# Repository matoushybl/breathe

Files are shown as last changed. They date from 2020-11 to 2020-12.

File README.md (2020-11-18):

# `app-template`

> Quickly set up a [`probe-run`] + [`defmt`] + [`flip-link`] embedded project

[`probe-run`]: https://crates.io/crates/probe-run
[`defmt`]: https://github.com/knurling-rs/defmt
[`flip-link`]: https://github.com/knurling-rs/flip-link

## Dependencies

#### 1. `flip-link`:

```console
$ cargo install flip-link
```

#### 2. `probe-run`:

``` console
$ cargo install probe-run
```

#### 3. [`cargo-generate`]:

```
$ cargo install cargo-generate
```

[`cargo-generate`]: https://crates.io/crates/cargo-generate

> *Note:* You can also just clone this repository instead of using `cargo-generate`, but this involves additional manual adjustments. [This flip-link CI patch](https://github.com/knurling-rs/flip-link/blob/main/.github/workflows/0001-configure-test-flip-link-app-for-nrf52840.patch) can serve as a reference on what to do.

## Setup

#### 1. Initialize the project template

``` console
$ cargo generate \
    --git https://github.com/knurling-rs/app-template \
    --branch main \
    --name my-app
```

If you look into your new `my-app` folder, you'll find that there are a few `TODO`s in the files marking the properties you need to set.

Let's walk through them together now.

#### 2. Set `probe-run` chip

Pick a chip from `probe-run --list-chips` and enter it into `.cargo/config.toml`.

If, for example, you have a nRF52840 Development Kit from one of [our workshops], replace `{{chip}}` with `nRF52840_xxAA`.

[our workshops]: https://github.com/ferrous-systems/embedded-trainings-2020

``` diff
 # .cargo/config.toml
 [target.'cfg(all(target_arch = "arm", target_os = "none"))']
-runner = "probe-run --chip {{chip}} --defmt"
+runner = "probe-run --chip nRF52840_xxAA --defmt"
```

#### 3. Adjust the compilation target

In `.cargo/config.toml`, pick the right compilation target for your board.

``` diff
 # .cargo/config.toml
 [build]
-target = "thumbv6m-none-eabi"    # Cortex-M0 and Cortex-M0+
-# target = "thumbv7m-none-eabi"    # Cortex-M3
-# target = "thumbv7em-none-eabi"   # Cortex-M4 and Cortex-M7 (no FPU)
-# target = "thumbv7em-none-eabihf" # Cortex-M4F and Cortex-M7F (with FPU)
+target = "thumbv7em-none-eabihf" # Cortex-M4F (with FPU)
```

#### 4. Add a HAL as a dependency

In `Cargo.toml`, list the Hardware Abstraction Layer (HAL) for your board as a dependency.

For the nRF52840 you'll want to use the [`nrf52840-hal`].

[`nrf52840-hal`]: https://crates.io/crates/nrf52840-hal

``` diff
 # Cargo.toml
 [dependencies]
-# some-hal = "1.2.3"
+nrf52840-hal = "0.11.0"
```

#### 5. Import your HAL

Now that you have selected a HAL, fix the HAL import in `src/lib.rs`

``` diff
 // my-app/src/lib.rs
-// use some_hal as _; // memory layout
+use nrf52840_hal as _; // memory layout
```

#### (6. Get a linker script)

Some HAL crates require that you manually copy over a file called `memory.x` from the HAL to the root of your project. For nrf52840-hal, this is done automatically so no action is needed. For other HAL crates, you can get it from your local Cargo folder, the default location is under:

```
~/.cargo/registry/src/
```

Not all HALs provide a memory.x file, you may need to write it yourself. Check the documentation for the HAL you are using.

#### 7. Run!

You are now all set to `cargo-run` your first `defmt`-powered application!
There are some examples in the `src/bin` directory.

Start by `cargo run`-ning `my-app/src/bin/hello.rs`:

``` console
$ # `rb` is an alias for `run --bin`
$ cargo rb hello
    Finished dev [optimized + debuginfo] target(s) in 0.03s
flashing program ..
DONE
resetting device
0.000000 INFO Hello, world!
(..)

$ echo $?
0
```

## Trying out the git version of defmt

This template is configured to use the latest crates.io release (the "stable" release) of the `defmt` framework.
To use the git version (the "development" version) of `defmt` follow these steps:

1. Install the *git* version of `probe-run`

``` console
$ cargo install --git https://github.com/knurling-rs/probe-run --branch main
```

2. Check which defmt version `probe-run` supports

``` console
$ probe-run --version
probe-run 0.1.4 (3521a42 2020-11-12)
supported defmt version: 3db6b41f08a5c866e6d6ed7103d01b0b0fe5a1f4
```

In the example output, the supported version is `3db6b41f08a5c866e6d6ed7103d01b0b0fe5a1f4`

3. Switch defmt dependencies to git: uncomment the last part of the root `Cargo.toml` and enter the hash reported by `probe-run --version`:

``` diff
-# [patch.crates-io]
-# defmt = { git = "https://github.com/knurling-rs/defmt", rev = "use defmt version reported by `probe-run --version`" }
-# defmt-rtt = { git = "https://github.com/knurling-rs/defmt", rev = "use defmt version reported by `probe-run --version`" }
-# defmt-test = { git = "https://github.com/knurling-rs/defmt", rev = "use defmt version reported by `probe-run --version`" }
-# panic-probe = { git = "https://github.com/knurling-rs/defmt", rev = "use defmt version reported by `probe-run --version`" }
+[patch.crates-io]
+defmt = { git = "https://github.com/knurling-rs/defmt", rev = "3db6b41f08a5c866e6d6ed7103d01b0b0fe5a1f4" }
+defmt-rtt = { git = "https://github.com/knurling-rs/defmt", rev = "3db6b41f08a5c866e6d6ed7103d01b0b0fe5a1f4" }
+defmt-test = { git = "https://github.com/knurling-rs/defmt", rev = "3db6b41f08a5c866e6d6ed7103d01b0b0fe5a1f4" }
+panic-probe = { git = "https://github.com/knurling-rs/defmt", rev = "3db6b41f08a5c866e6d6ed7103d01b0b0fe5a1f4" }
```

You are now using the git version of `defmt`!

**NOTE** there may have been breaking changes between the crates.io version and the git version; you'll need to fix those in the source code.

## Support

`app-template` is part of the [Knurling] project, [Ferrous Systems]' effort at
improving tooling used to develop for embedded systems.

If you think that our work is useful, consider sponsoring it via [GitHub
Sponsors].

## License

Licensed under either of

- Apache License, Version 2.0 ([LICENSE-APACHE](LICENSE-APACHE) or
  http://www.apache.org/licenses/LICENSE-2.0)

- MIT license ([LICENSE-MIT](LICENSE-MIT) or http://opensource.org/licenses/MIT)

at your option.

### Contribution

Unless you explicitly state otherwise, any contribution intentionally submitted
for inclusion in the work by you, as defined in the Apache-2.0 license, shall be
licensed as above, without any additional terms or conditions.

[Knurling]: https://knurling.ferrous-systems.com
[Ferrous Systems]: https://ferrous-systems.com/
[GitHub Sponsors]: https://github.com/sponsors/knurling-rs

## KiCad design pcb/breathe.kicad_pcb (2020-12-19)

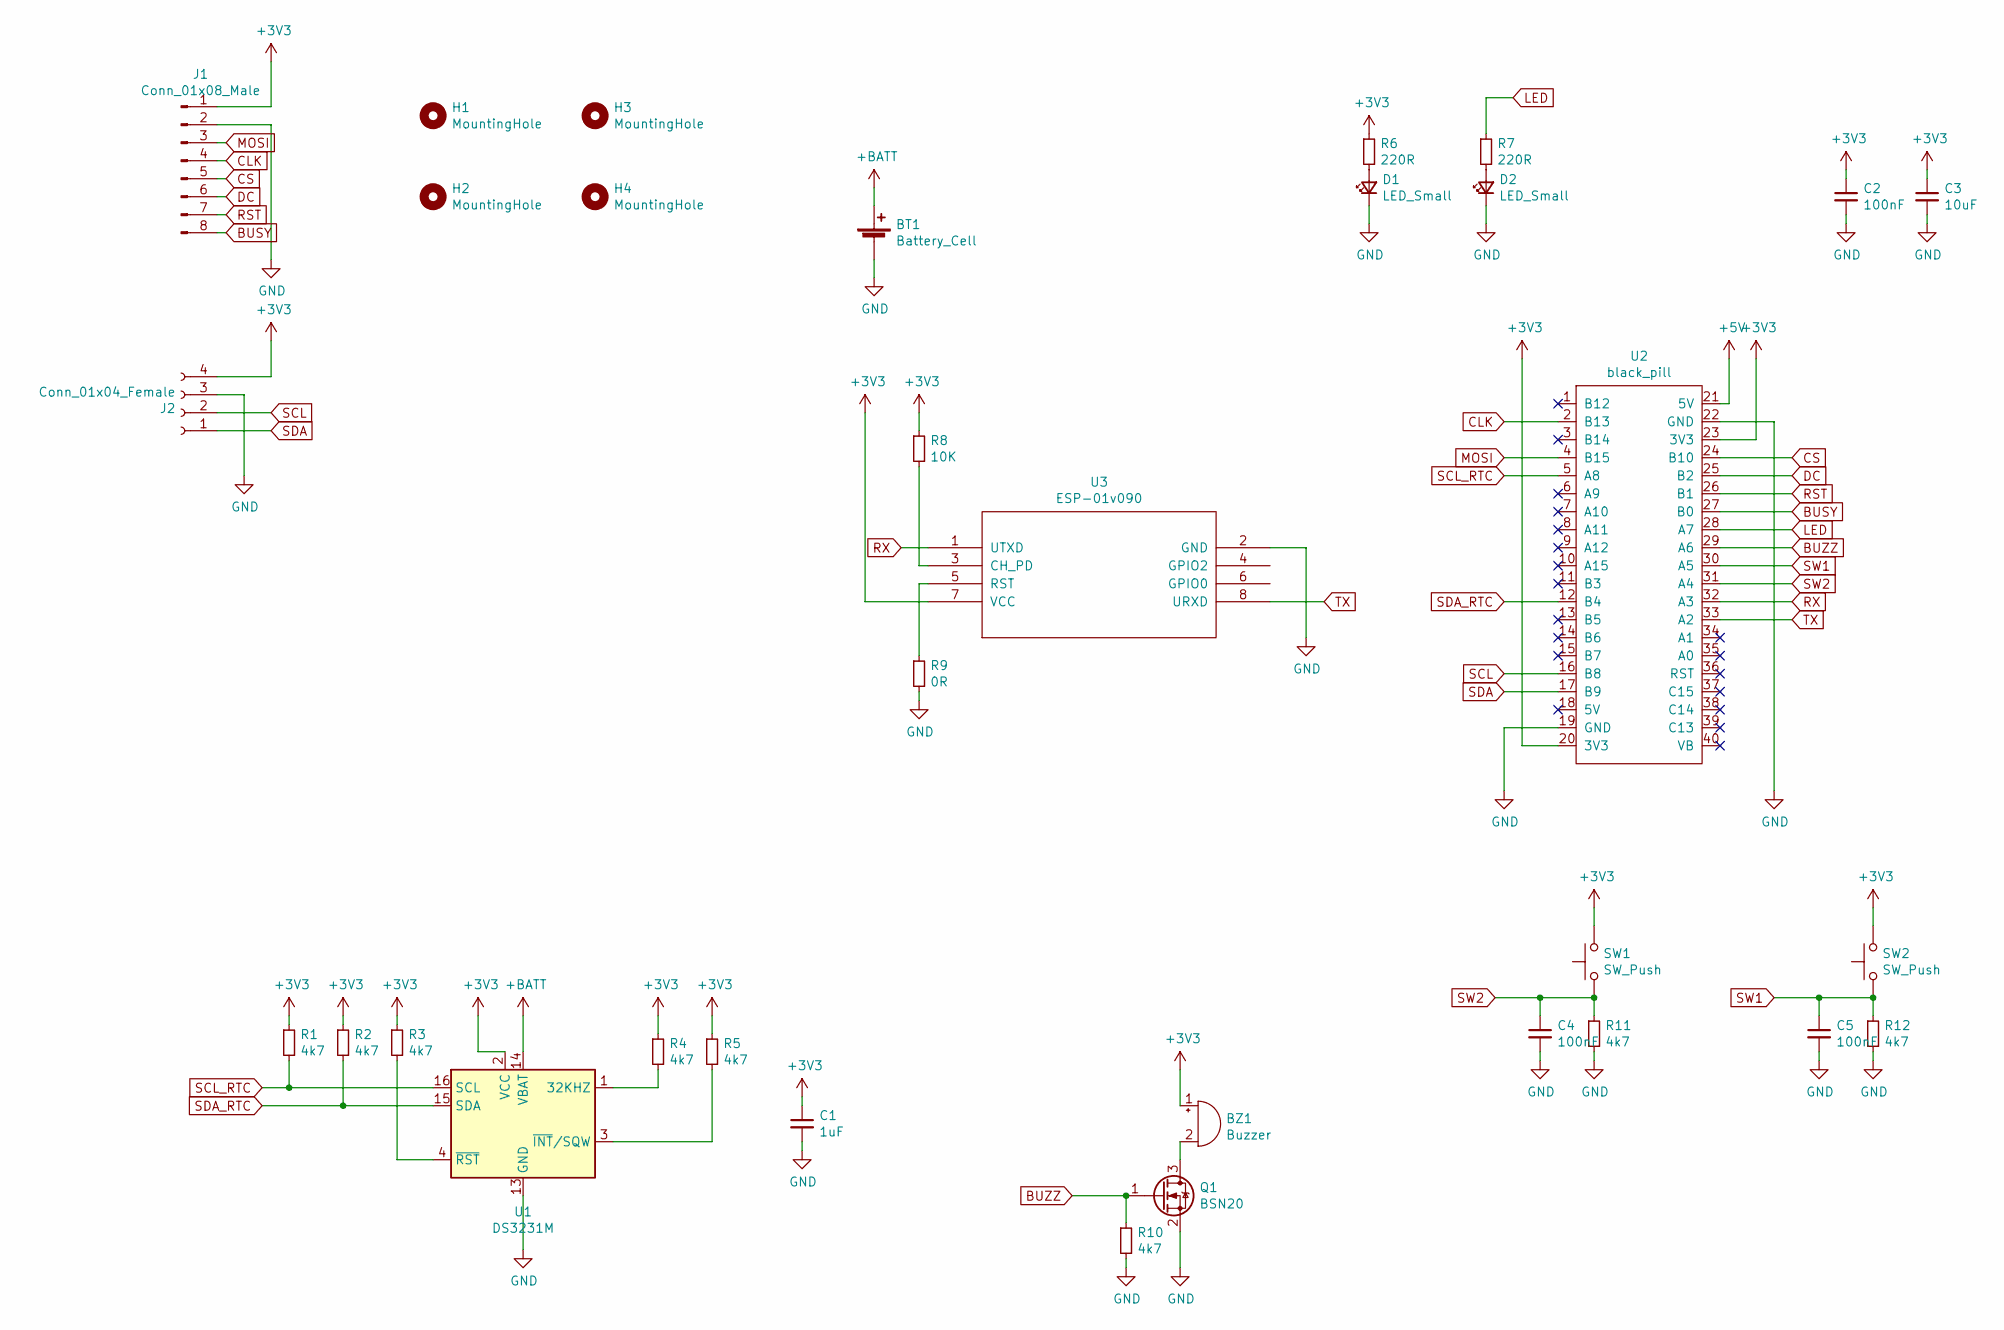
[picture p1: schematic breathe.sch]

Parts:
BT1: Battery_Cell; BatteryHolder_Keystone_1060_1x2032
BZ1: Buzzer; Buzzer_12x9.5RM7.6
C1: 1uF; C_0805_2012Metric_Pad1.18x1.45mm_HandSolder
C2, C4, C5: 100nF; C_0805_2012Metric_Pad1.18x1.45mm_HandSolder
C3: 10uF; C_0805_2012Metric_Pad1.18x1.45mm_HandSolder
D1, D2: LED_Small; LED_0805_2012Metric_Pad1.15x1.40mm_HandSolder
H1, H2, H3, H4: MountingHole; MountingHole_2.7mm_M2.5
J1: Conn_01x08_Male; PinHeader_1x08_P2.54mm_Vertical
J2: Conn_01x04_Female; PinHeader_1x04_P2.54mm_Horizontal
Q1: BSN20; SOT-23
R1, R2, R3, R4, R5, R10, R11, R12: 4k7; R_0805_2012Metric_Pad1.20x1.40mm_HandSolder
R6, R7: 220R; R_0805_2012Metric_Pad1.20x1.40mm_HandSolder
R8: 10K; R_0805_2012Metric_Pad1.20x1.40mm_HandSolder
R9: 0R; R_0805_2012Metric_Pad1.20x1.40mm_HandSolder
SW1, SW2: SW_Push; SW_PUSH_6mm
U1: DS3231M; SOIC-16W_7.5x10.3mm_P1.27mm
U2: black_pill
U3: ESP-01v090; ESP-01

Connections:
+3V3: BZ1.1 (-), C1.1, C2.1, C3.1, J1.1, J2.4, R1.1, R2.1, R3.1, R4.1, R5.1, R6.1, R8.1, SW1.2, SW2.2, U1.2 (VCC), U2.20 (3V3), U2.23 (3V3), U3.7 (VCC)
+BATT: BT1.1 (+), U1.14 (VBAT)
BUSY: J1.8, U2.27 (B0)
BUZZ: Q1.1 (G), R10.1, U2.29 (A6)
CLK: J1.4, U2.2 (B13)
CS: J1.5, U2.24 (B10)
DC: J1.6, U2.25 (B2)
GND: BT1.2 (-), C1.2, C2.2, C3.2, C4.2, C5.2, D1.1 (K), D2.1 (K), J1.2, J2.3, Q1.2 (S), R9.2, R10.2, R11.2, R12.2, U1.5 (GND), U1.6 (GND), U1.7 (GND), U1.8 (GND), U1.9 (GND), U1.10 (GND), U1.11 (GND), U1.12 (GND), U1.13 (GND), U2.19 (GND), U2.22 (GND), U3.2 (GND)
LED: R7.1, U2.28 (A7)
MOSI: J1.3, U2.4 (B15)
unnamed: BZ1.2 (+), Q1.3 (D)
unnamed: D1.2 (A), R6.2
unnamed: D2.2 (A), R7.2
unnamed: R3.2, U1.4 (~RST)
unnamed: R4.2, U1.1 (32KHZ)
unnamed: R5.2, U1.3 (~INT~/SQW)
unnamed: R8.2, U3.3 (CH_PD)
unnamed: R9.1, U3.5 (RST)
RST: J1.7, U2.26 (B1)
RX: U2.32 (A3), U3.1 (UTXD)
SCL: J2.2, U2.16 (B8)
SCL_RTC: R1.2, U1.16 (SCL), U2.5 (A8)
SDA: J2.1, U2.17 (B9)
SDA_RTC: R2.2, U1.15 (SDA), U2.12 (B4)
SW1: C5.1, R12.1, SW2.1, U2.30 (A5)
SW2: C4.1, R11.1, SW1.1, U2.31 (A4)
TX: U2.33 (A2), U3.8 (URXD)

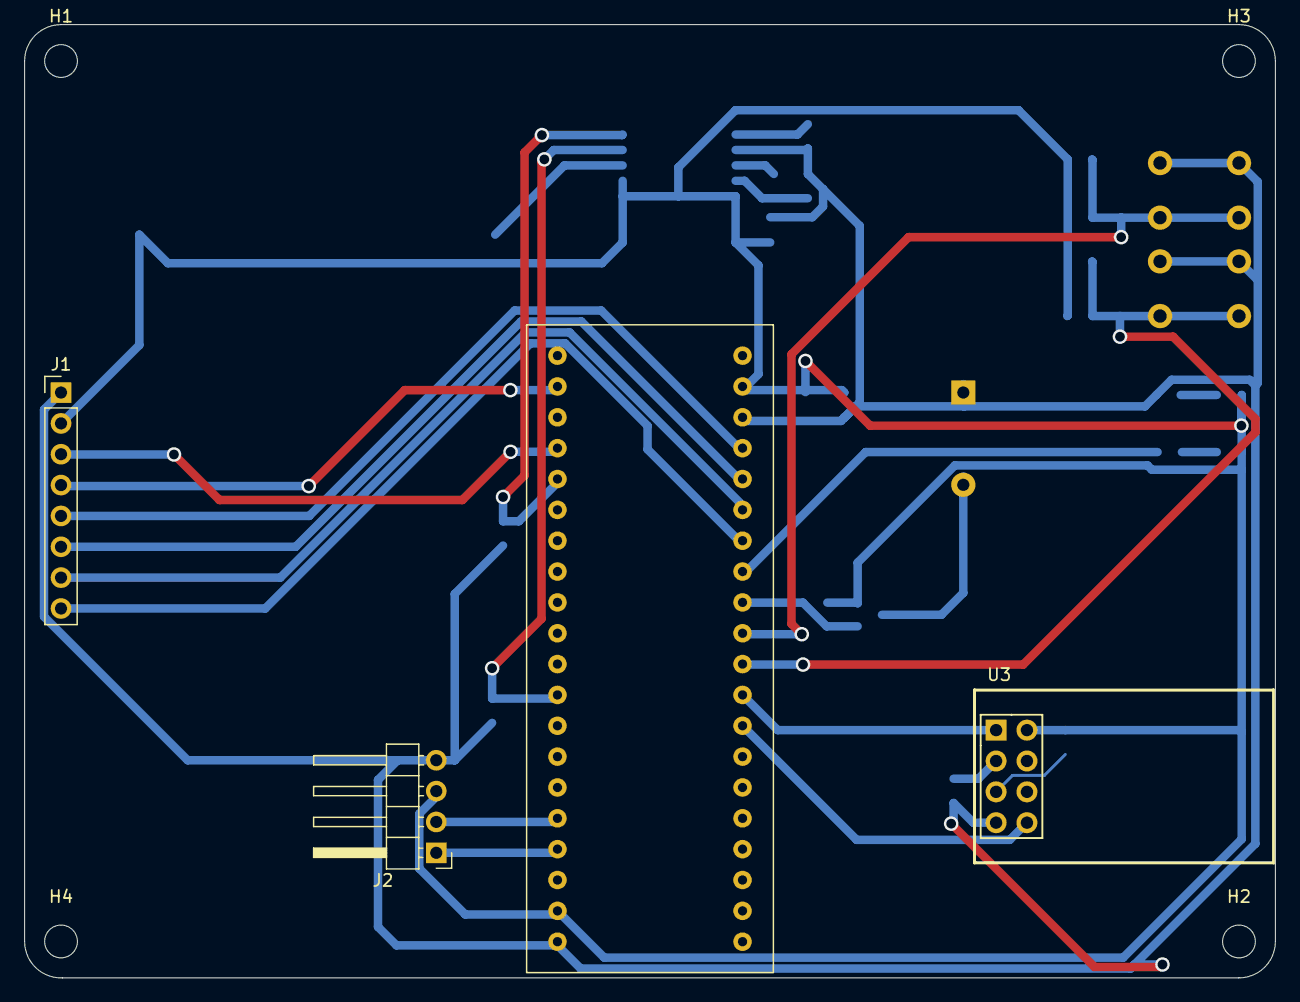
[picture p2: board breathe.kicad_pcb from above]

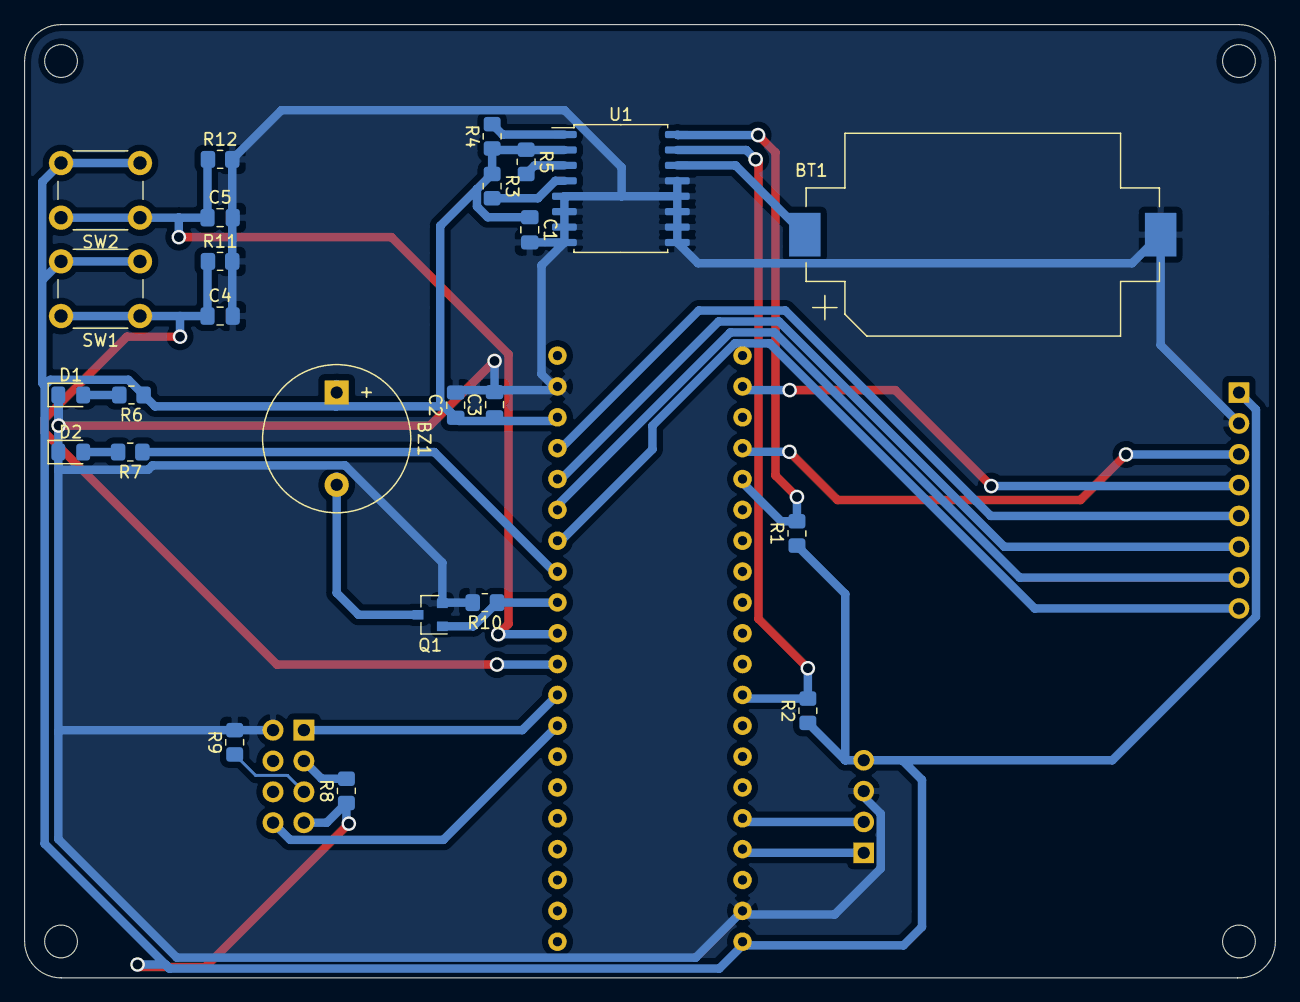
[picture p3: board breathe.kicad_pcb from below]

Board: 2 copper layers, 103.0 x 78.5 mm, 33 parts (25 on the bottom side), 27 nets.

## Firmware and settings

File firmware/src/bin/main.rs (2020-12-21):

#![no_main]
#![no_std]

use breathe_rs as _; // global logger + panicking-behavior + memory layout
use cortex_m::peripheral::DWT;
use rtic::cyccnt::U32Ext as _;

use stm32f4xx_hal as hal;

use breathe_rs::scd30::{SensorData, SCD30};
// use ds1307::{Datelike, Ds1307, NaiveDate, Rtcc, Timelike};
use stm32f4xx_hal::gpio::gpiob::{PB, PB13, PB15, PB4, PB8, PB9};
use stm32f4xx_hal::gpio::{
    Alternate, AlternateOD, Floating, Input, Output, PushPull, AF4, AF5, AF9,
};
use stm32f4xx_hal::i2c::I2c;
use stm32f4xx_hal::prelude::*;
use stm32f4xx_hal::stm32;
use stm32f4xx_hal::stm32::{I2C1, I2C3};

use breathe_rs::rendering::{Renderer, State};
use breathe_rs::usb_parser::USBDateBuffer;
use ds323x::ic::DS3231;
use ds323x::interface::I2cInterface;
use ds323x::{Datelike, Ds323x, NaiveDate, NaiveDateTime, Rtcc, Timelike};
use embedded_hal::blocking::delay::DelayMs;
use epd_waveshare::epd4in2::{Display4in2, EPD4in2};
use epd_waveshare::prelude::WaveshareDisplay;
use stm32f4xx_hal::gpio::gpioa::{PA, PA8};
use stm32f4xx_hal::otg_fs::*;
use stm32f4xx_hal::rcc::Clocks;
use stm32f4xx_hal::spi::{NoMiso, Spi};
use stm32f4xx_hal::timer::Timer;
use usb_device::class_prelude::UsbBusAllocator;
use usb_device::prelude::*;
use usbd_serial::SerialPort;

const SECOND: u32 = 84_000_000;

const DISPLAY_REFRESH: u32 = SECOND;
const BLINK_PERIOD: u32 = SECOND / 10;
const UPDATE_SENSOR: u32 = 2 * SECOND;

const DISPLAY_REFRESH_COUNT: u16 = 20;

const BEEP_PERIOD: u16 = 10 * 60; // 10 minutes
const BEEP_TIME: u32 = SECOND / 20;
const BEEP_CO2_LEVEL: f32 = 1500.0;

const PRESSURE_OFFSET: u16 = 1031; // Brno, 17.11

struct Delay {
    timer: Timer<stm32::TIM10>,
}

impl Delay {
    pub fn new(tim: stm32::TIM10, clocks: Clocks) -> Self {
        let timer = Timer::tim10(tim, 1000.hz(), clocks);
        Self { timer }
    }
}

impl DelayMs<u16> for Delay {
    fn delay_ms(&mut self, ms: u16) {
        let _ = self.timer.wait(); // clear UIF flag and reset counting
        for _ in 0..ms {
            nb::block!(self.timer.wait());
        }
    }
}

impl DelayMs<u8> for Delay {
    fn delay_ms(&mut self, ms: u8) {
        let _ = self.timer.wait(); // clear UIF flag and reset counting
        for _ in 0..ms {
            nb::block!(self.timer.wait());
        }
    }
}

pub type EPDisplay = Renderer<
    SPI,
    PB<Output<PushPull>>,
    PB<Input<Floating>>,
    PB<Output<PushPull>>,
    PB<Output<PushPull>>,
>;
type SPI = Spi<stm32::SPI2, (PB13<Alternate<AF5>>, NoMiso, PB15<Alternate<AF5>>)>;

type CO2Sensor = SCD30<I2c<I2C1, (PB8<AlternateOD<AF4>>, PB9<AlternateOD<AF4>>)>>;
type RTC = Ds323x<I2cInterface<I2c<I2C3, (PA8<AlternateOD<AF4>>, PB4<AlternateOD<AF9>>)>>, DS3231>;

#[rtic::app(device = stm32f4xx_hal::stm32, peripherals = true, monotonic = rtic::cyccnt::CYCCNT)]
const APP: () = {
    struct Resources {
        led: PA<Output<PushPull>>,
        sensor: CO2Sensor,
        display: EPDisplay,
        spi: SPI,
        rtc: RTC,
        state: State,
        #[init(0)]
        refresh_second_counter: u16,
        #[init(0)]
        beeper_second_counter: u16,
        #[init(false)]
        levels_exceeded: bool,
        beeper: PA<Output<PushPull>>,
        serial: SerialPort<'static, UsbBusType>,
        usb_dev: UsbDevice<'static, UsbBusType>,
        date_buffer: USBDateBuffer,
    }

    #[init(schedule = [blink, update_sensor, refresh_display, beep])]
    fn init(cx: init::Context) -> init::LateResources {
        static mut EP_MEMORY: [u32; 1024] = [0; 1024];
        static mut USB_BUS: Option<UsbBusAllocator<UsbBusType>> = None;

        let mut core: rtic::Peripherals = cx.core;
        let device: stm32::Peripherals = cx.device;

        // enable CYCCNT
        core.DCB.enable_trace();
        DWT::unlock();
        core.DWT.enable_cycle_counter();

        let rcc = device.RCC.constrain().cfgr.sysclk(84.mhz()).hclk(84.mhz());
        let clocks = rcc.freeze();

        let gpioa = device.GPIOA.split();
        let gpiob = device.GPIOB.split();
        let _gpioc = device.GPIOC.split();

        let mut led = gpioa.pa7.into_push_pull_output().downgrade();
        let mut beeper = gpioa.pa6.into_push_pull_output().downgrade();

        let sda = gpiob.pb9.into_alternate_af4_open_drain();
        let scl = gpiob.pb8.into_alternate_af4_open_drain();
        let cs = gpiob.pb10.into_push_pull_output().downgrade();
        let spiclk = gpiob.pb13.into_alternate_af5();
        let spimosi = gpiob.pb15.into_alternate_af5();
        let dc = gpiob.pb2.into_push_pull_output().downgrade();
        let busy = gpiob.pb0.into_floating_input().downgrade();
        let rst = gpiob.pb1.into_push_pull_output().downgrade();

        let sda3 = gpiob.pb4.into_alternate_af9_open_drain();
        let scl3 = gpioa.pa8.into_alternate_af4_open_drain();

        let i2c3 = I2c::i2c3(device.I2C3, (scl3, sda3), 100.khz(), clocks);
        let mut rtc = ds323x::Ds323x::new_ds3231(i2c3);

        let initial_datetime = rtc.get_datetime().unwrap();

        let mut spi = hal::spi::Spi::spi2(
            device.SPI2,
            (spiclk, NoMiso, spimosi),
            embedded_hal::spi::MODE_0,
            4.mhz().into(),
            clocks,
        );

        let mut delay = Delay::new(device.TIM10, clocks);

        beeper.set_high().unwrap();
        delay.delay_ms(100u8);
        beeper.set_low().unwrap();

        let epd4in2 =
            EPD4in2::new(&mut spi, cs, busy, dc, rst, &mut delay).expect("eink initalize error");
        let display = Display4in2::default();
        let mut display = Renderer::new(&mut spi, epd4in2, display);
        display.render_boot(&mut spi);

        // the i2c must be initialized after all of the pins are initialized, otherwise it won't boot after startup.
        // There might be another reason, but the solution is to reorder initialization of peripherals.
        let i2c = hal::i2c::I2c::i2c1(device.I2C1, (scl, sda), 45.khz(), clocks);
        let mut sensor = SCD30::init(i2c);

        delay.delay_ms(2000u16);

        if let Ok(v) = sensor.read_fw_version() {
            defmt::error!("maj: {:u8} min: {:u8}", v[0], v[1]);
        }

        sensor
            .start_continuous_measurement(PRESSURE_OFFSET)
            .unwrap();

        let usb = USB {
            usb_global: device.OTG_FS_GLOBAL,
            usb_device: device.OTG_FS_DEVICE,
            usb_pwrclk: device.OTG_FS_PWRCLK,
            pin_dm: gpioa.pa11.into_alternate_af10(),
            pin_dp: gpioa.pa12.into_alternate_af10(),
        };

        *USB_BUS = Some(UsbBus::new(usb, &mut EP_MEMORY[..]));

        let serial = usbd_serial::SerialPort::new(USB_BUS.as_ref().unwrap());

        let usb_dev = UsbDeviceBuilder::new(USB_BUS.as_ref().unwrap(), UsbVidPid(0x16c0, 0x27dd))
            .manufacturer("Fake company")
            .product("Serial port")
            .serial_number("TEST")
            .device_class(usbd_serial::USB_CLASS_CDC)
            .build();

        let now = cx.start;
        cx.schedule.blink(now + BLINK_PERIOD.cycles()).unwrap();
        cx.schedule
            .update_sensor(now + UPDATE_SENSOR.cycles())
            .unwrap();
        cx.schedule
            .refresh_display(now + DISPLAY_REFRESH.cycles())
            .unwrap();

        cx.schedule
            .beep(now + SECOND.cycles())
            .unwrap();

        init::LateResources {
            led,
            sensor,
            display,
            spi,
            rtc,
            beeper,
            state: State::default(),
            serial,
            usb_dev,
            date_buffer: USBDateBuffer::new(),
        }
    }

    #[idle(resources = [date_buffer, rtc])]
    fn idle(cx: idle::Context) -> ! {
        let mut date_buffer = cx.resources.date_buffer;
        let mut rtc = cx.resources.rtc;
        loop {
            date_buffer.lock(|buf: &mut USBDateBuffer| {
                if buf.is_date_available() {
                    let date = buf.get_datetime();
                    rtc.lock(|rtc: &mut RTC| {
                        rtc.set_datetime(&date).unwrap();
                    });
                    buf.clear();
                }
            });
        }
    }

    #[task(binds = OTG_FS, resources = [serial, usb_dev, date_buffer])]
    fn usb_handler(cx: usb_handler::Context) {
        let serial: &mut SerialPort<UsbBusType> = cx.resources.serial;
        let usb_dev: &mut UsbDevice<UsbBusType> = cx.resources.usb_dev;
        let date_buffer: &mut USBDateBuffer = cx.resources.date_buffer;
        if !usb_dev.poll(&mut [serial]) {
            return;
        }
        let mut buf = [0u8; 64];

        match serial.read(&mut buf[..]) {
            Ok(count) => {
                date_buffer.recv(&buf[..count]);
                // for c in buf[..count].iter() {
                //     serial.write(&[*c]).unwrap();
                //     defmt::warn!("data {:u8}", c);
                // }
                // count bytes were read to &buf[..count]
            }
            Err(UsbError::WouldBlock) => {
                // defmt::debug!("would block.");
            } // No data received
            Err(_) => {
                defmt::warn!("err.");
            } // An error occurred
        };
    }

    #[task(resources = [led], schedule = [blink])]
    fn blink(cx: blink::Context) {
        let led: &mut PA<Output<PushPull>> = cx.resources.led;
        if led.is_low().unwrap() {
            led.set_high().unwrap();
        } else {
            led.set_low().unwrap();
        }

        cx.schedule
            .blink(cx.scheduled + BLINK_PERIOD.cycles())
            .unwrap();
    }

    #[task(resources = [sensor, state, rtc, levels_exceeded], schedule = [update_sensor])]
    fn update_sensor(cx: update_sensor::Context) {
        let sensor: &mut CO2Sensor = cx.resources.sensor;
        let state: &mut State = cx.resources.state;
        let rtc: &mut RTC = cx.resources.rtc;
        let levels_exceeded: &mut bool = cx.resources.levels_exceeded;

        cx.schedule
            .update_sensor(cx.scheduled + UPDATE_SENSOR.cycles())
            .unwrap();
        if !sensor.get_data_ready().unwrap_or(false) {
            return;
        }

        if let Ok(data) = sensor.read_measurement() {
            if data.co2 > BEEP_CO2_LEVEL {
                *levels_exceeded = true;
            }
            state.update_sensor_data(data);
        }

        state.datetime = rtc.get_datetime().unwrap();
    }

    #[task(resources = [display, spi, state, refresh_second_counter], schedule = [refresh_display])]
    fn refresh_display(cx: refresh_display::Context) {
        let display: &mut EPDisplay = cx.resources.display;
        let spi: &mut SPI = cx.resources.spi;
        let state: &mut State = cx.resources.state;
        let second_counter: &mut u16 = cx.resources.refresh_second_counter;

        if *second_counter == DISPLAY_REFRESH_COUNT {
            display.render_data(spi, state);
            *second_counter = 0;
        } else {
            *second_counter += 1;
        }

        cx.schedule
            .refresh_display(cx.scheduled + DISPLAY_REFRESH.cycles())
            .unwrap();
    }

    #[task(resources = [beeper, beeper_second_counter, levels_exceeded], schedule = [beep, beep_off])]
    fn beep(cx: beep::Context) {
        let second_counter: &mut u16 = cx.resources.beeper_second_counter;
        let beeper: &mut PA<Output<PushPull>> = cx.resources.beeper;
        let levels_exceeded: &mut bool = cx.resources.levels_exceeded;

        if *second_counter > BEEP_PERIOD {
            *second_counter = 0;
            if *levels_exceeded {
                beeper.set_high().unwrap();
                *levels_exceeded = true;
            }
        } else {
            *second_counter += 1;
        }

        cx.schedule
            .beep_off(cx.scheduled + BEEP_TIME.cycles())
            .unwrap();

        cx.schedule
            .beep(cx.scheduled + SECOND.cycles())
            .unwrap();
    }

    #[task(resources = [beeper])]
    fn beep_off(cx: beep_off::Context) {
        let beeper: &mut PA<Output<PushPull>> = cx.resources.beeper;

        beeper.set_low().unwrap();
    }

    extern "C" {
        fn EXTI0();
    }
};

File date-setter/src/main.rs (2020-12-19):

use std::time::{Duration, Instant};
use serialport::FlowControl;
use chrono::{DateTime, NaiveDateTime, Utc, Timelike, Local, Datelike};
use byteorder::{LittleEndian, ByteOrder};
use std::io::Write;

fn main() {
    println!("Hello, world!");
    let mut settings = serialport::SerialPortSettings::default();
    settings.baud_rate = 115200;
    settings.timeout = Duration::from_millis(10);
    settings.flow_control = FlowControl::None;
    let mut port = serialport::open_with_settings("/dev/ttyACM0", &settings).unwrap();

    let date = Local::now().naive_local();
    let mut buffer = [0u8; 8];
    // 1 - hour, 1 - minute, 1 - second, 1 - day, 1 - month, 2 - year
    buffer[0] = 0xaa;
    buffer[1] = date.hour() as u8;
    buffer[2] = date.minute() as u8;
    buffer[3] = date.second() as u8;
    buffer[4] = date.day() as u8;
    buffer[5] = date.month() as u8;
    LittleEndian::write_u16(&mut buffer[6..], date.year() as u16);
    println!("date: {:?}", buffer);

    port.write(&buffer).unwrap();
}
